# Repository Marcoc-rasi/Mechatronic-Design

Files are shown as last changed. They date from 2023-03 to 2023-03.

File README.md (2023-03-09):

# Mechatronic-Design
I worked together with a team of engineers on a robot that picks up tennis balls,the robot was made to function autonomously through the following systems
1- the power was supplied by a battery
2- the advance of the robot was carried out with direct current motors connected to a gear system to increase its torque, the speed and direction of rotation were controlled with an H bridge
3.- The blades work with a direct current motor, the rotation of the blades is activated through an infrared sensor, which detects when a ball enters the ramp and makes it rotate. This same sensor also helps us to stop the ramp in the starting position to insert a new ball.
4.- the robot has ultrasonic sensors which are used to detect obstacles and avoid them
5.- The color sensor located in the lower part of the car is used to determine the area of operation of the robot, we take samples of the colors of the interior of the tennis court, the lines of the court and the exterior of the court.
6.- to locate the balls and go to them, the robot uses an automatic vision system, which divides the view of the camera (cell phone) into two planes, if it finds a circular shape of the color of the tennis ball, in In one of these two planes, left or right, the robot will turn until it leaves the ball in the center of the division, in this way it always goes to a ball centering the entrance of the blades.

Two microcontrollers were used mainly due to two reasons, the first is regarding the ultrasonic sensors, since we had more than one, and these need a certain time to measure the distance, which left all the other processes pending. the vision and the ultrasonic sensors, these two were controlled by the esp32, and the vision was executed in OpenCV on the cell phone, sending a signal via bluetooth to the esp32 which communicated with Arduino through serial communication to generate the rotation of the robot

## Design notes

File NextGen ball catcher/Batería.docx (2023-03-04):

Batería:

Opciones:

- Power Bank
- Arreglo de Baterías 18650

Power Bank

Características:

5V

Capacidad: ~

Arreglo de Baterías 3S:

Voltaje: 3.7*3=11.1V

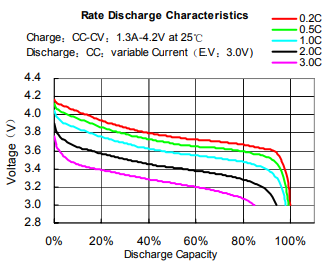
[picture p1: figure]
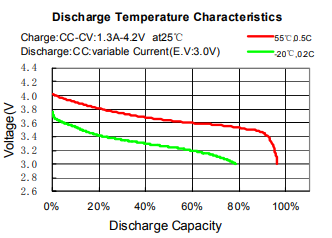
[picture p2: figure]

Estimaciones de porcentaje de carga de batería 18650

% de carga | Voltaje [V]
0 | 3 a 3.35
25 | 3.36 a 3.39
50 | 3.4 a 3.56
75 | 3.57 a 3.69
100 | >3.7

Estimaciones de porcentaje de carga para configuración 3S

% de carga | Voltaje [V]
0 | 9 a 10.05
25 | 10.06 a 10.17
50 | 10.18 a 10.68
100 | > 11.1

Nivel de carga de la batería950

Opciones:

- Módulo de nivel de carga de batería
- Medidor de voltaje / mostrar en GUI
- Arreglo de LEDs y Diodos Zener

Módulo de nivel de carga de batería | Medidor de voltaje | Arreglo de LEDs y Diodos Zener
- Para Baterías de Litio - Sólo requiere instalación - Costo estimado:$64 | - Para cualquier tipo de batería - Requiere instrumentación e implementación - Costo estimado: | - Para cualquier tipo de batería - Requiere cálculos - Costo estimado $25

Módulo de nivel de carga de batería

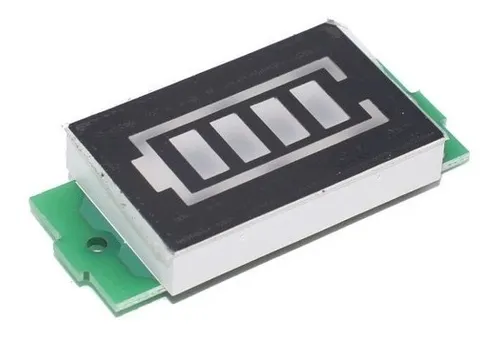
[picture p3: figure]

Medidor de voltaje

Arreglo de LEDs y Diodos Zener

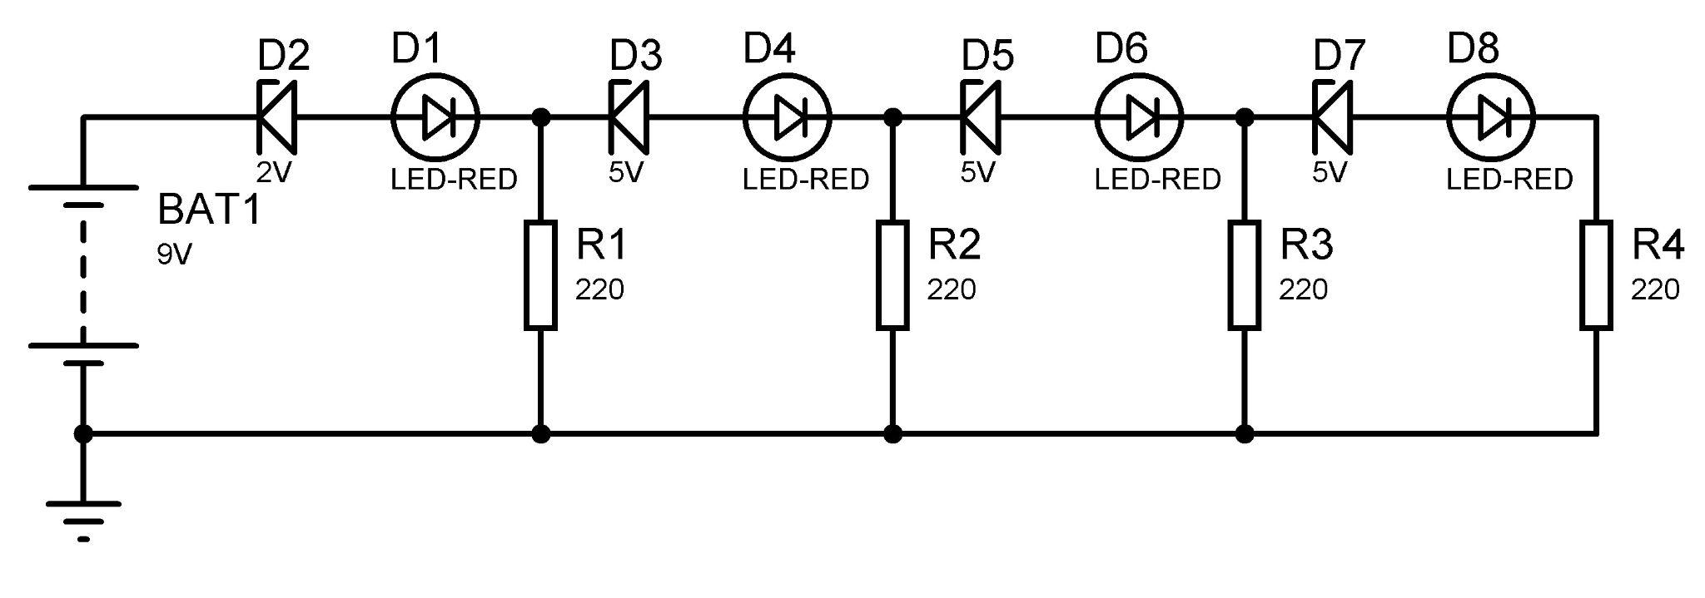
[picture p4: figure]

Microsoft Word - 18650H-2600mAh.doc (ineltro.ch) (https://www.ineltro.ch/media/downloads/SAAItem/45/45958/36e3e7f3-2049-4adb-a2a7-79c654d92915.pdf)

Indicador Led Carga De Bateria Litio Configurable Hasta 8s | MercadoLibre (https://articulo.mercadolibre.com.mx/MLM-754046522-indicador-led-carga-de-bateria-litio-configurable-hasta-8s-_JM)

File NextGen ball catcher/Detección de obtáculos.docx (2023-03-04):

Detección de obstáculos

Alternativas

- Módulo infrarrojo
- Circuito infrarrojo
- Láser

Módulo infrarrojo | Circuito infrarrojo | Módulo Láser
- Implementación sencilla - Distancia variable - Costo: $67 | - Requiere armado del circuito - Costo: $10 | - Implementación sencilla - Costo: 25

Módulo infrarrojo:

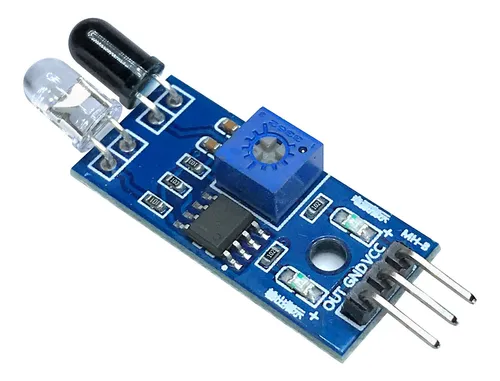
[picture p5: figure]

Módulo De Sensor Ir Infrarrojo Detector Obstaculos Arduino | MercadoLibre (https://articulo.mercadolibre.com.mx/MLM-826296559-modulo-de-sensor-ir-infrarrojo-detector-obstaculos-arduino-_JM)

Circuito Infrarrojo

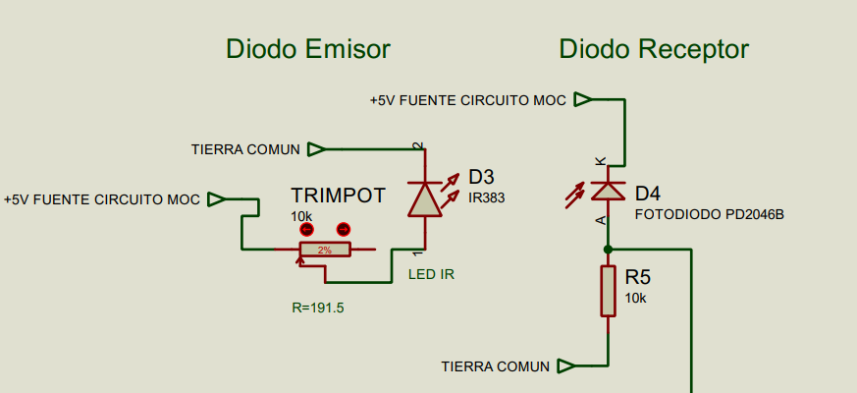
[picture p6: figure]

Láser

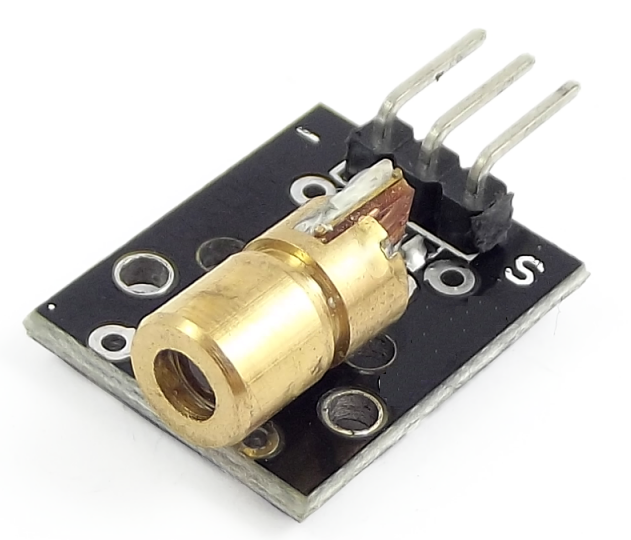
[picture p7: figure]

Módulo Sensor Laser KY-008 | SANDOROBOTICS (https://sandorobotics.com/producto/hr0021/)

Se seleccionó la opción del circuito de sensores infrarrojos, por el costo y la sencillez de armado y diseño, este circuito se pondrá a prueba para calibrar su funcionamiento

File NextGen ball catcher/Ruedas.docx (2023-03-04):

Descripción de la cancha

El área de trabajo del robot es una mitad de la cancha de tenis la cual cuenta con una superficie despejada, lisa y limpia, que no presenta irregularidades de ningún tipo debido a la seguridad de los deportistas. En la siguiente figura se muestra un ejemplo de cancha de tenis.

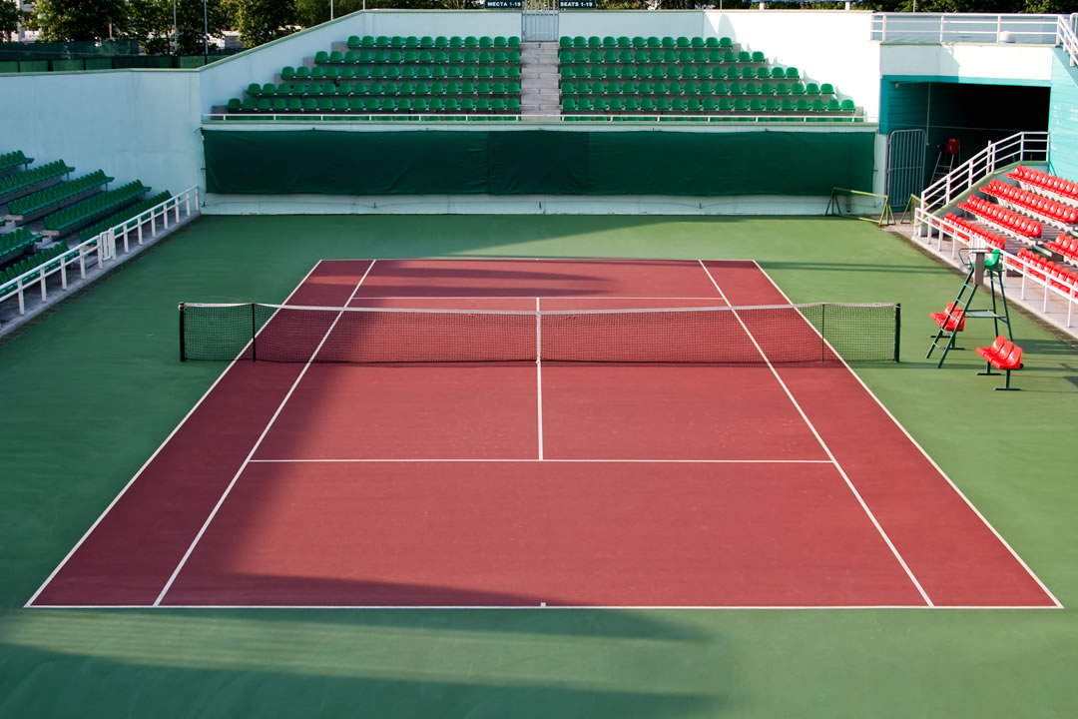
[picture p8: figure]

Comparativa de los diferentes tipos de ruedas

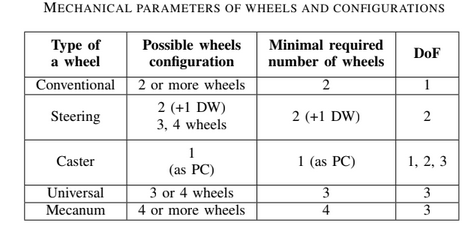
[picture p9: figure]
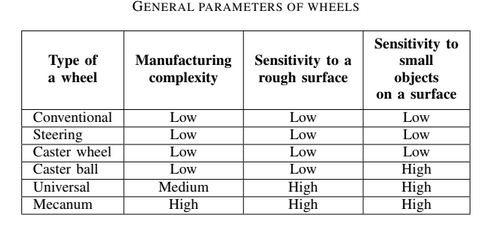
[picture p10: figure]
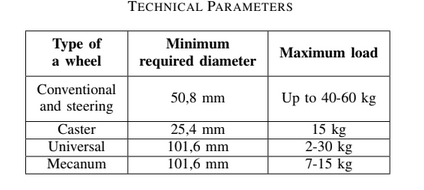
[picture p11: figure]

Selección de ruedas

Con ayuda de la comparativa se pudo observar que las ruedas que mejor se adaptan al prototipo de robot recoge pelotas de tenis son las convencionales, omnidireccionales y locas, debido a la que soportan mayor carga, su manufactura no es compleja por lo que los costos a comparación de las mecanum bajan significativamente, también soportan superficies más ásperas, como las canchas de tenis y son más resistentes que unas mecanum. Sin embargo, es necesario ver cuál es la combinación que soluciona mejor y con un menor costo la necesidad del robot.

Ruedas en el mercado

Convencionales

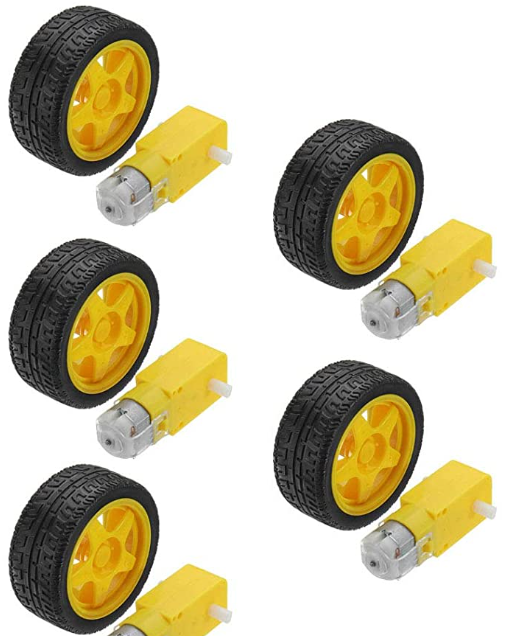
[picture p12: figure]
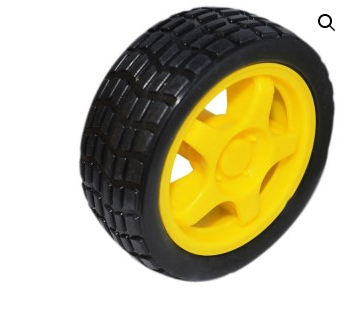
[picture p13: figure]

DollaTek 5 ruedas de plástico robot de coche inteligente con motor | Par de Llantas para Motorreductor de Plástico 65x26mm
Materiales: plástico + metal + goma. Relación de transmisión de reducción: 1:48 Voltaje de funcionamiento: 3-6 V. Par de torsión: 5.5kg/cm(6v) Tamaño: 70 x 27 x 23 mm (motor) Diámetro: 65 mm (rueda). Ancho: 27 mm (rueda) | Estas llantas o ruedas se usan comúnmente con los motorreductores de plástico, cuentan con unas dimensiones de de 65mm de diámetro exterior por 26mm de ancho. Son una opción perfecta para sustituir sus llantas gastadas así como para usarlas en motores de doble eje.
amazo-DollaTek (https://www.amazon.com.mx/DollaTek-pl%C3%A1stico-inteligente-engranaje-Arduino/dp/B081JM5WN8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) | Sandorobotics (https://sandorobotics.com/producto/hr0241/)

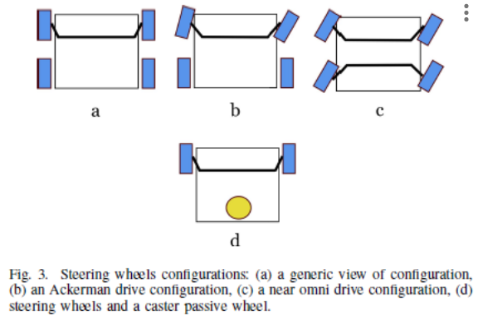
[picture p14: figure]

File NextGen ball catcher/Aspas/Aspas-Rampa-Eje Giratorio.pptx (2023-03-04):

## Aspas

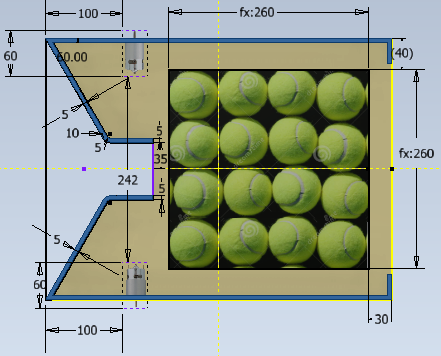
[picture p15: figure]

Independientemente del material las dimensiones serían:
Ancho: 3 mm
Largo: 100 mm
Alto: 80 mm
Eje Diametro 3 mm

Cambiar el diseño de la cabina donde entrarán las pelotas

## Material y Dimensión - Aspas y Eje

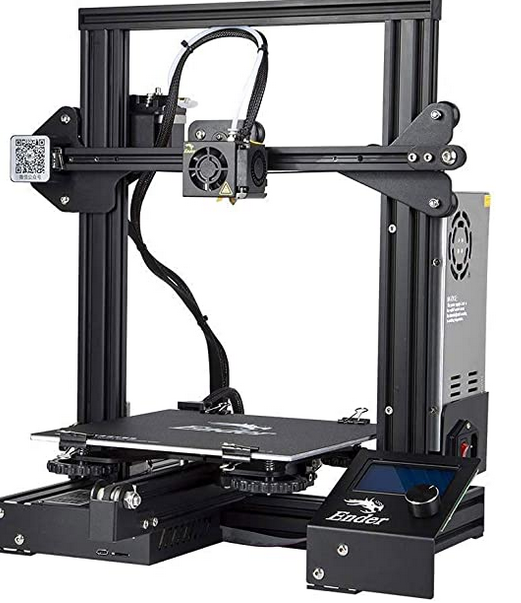
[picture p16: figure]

Impresión 3D: Ender 3

Detalles: Filamento Ácido poliláctico
- Precio - 430 $
- Dimensiones 1.75 mm diametro

- Diseños más complejos y elaborados
- Podemos elegir el grosor que más nos convenga.
- Da un aspecto profesional

- Más caro que las demás propuestas
- No muchos poseen una impresora 3D

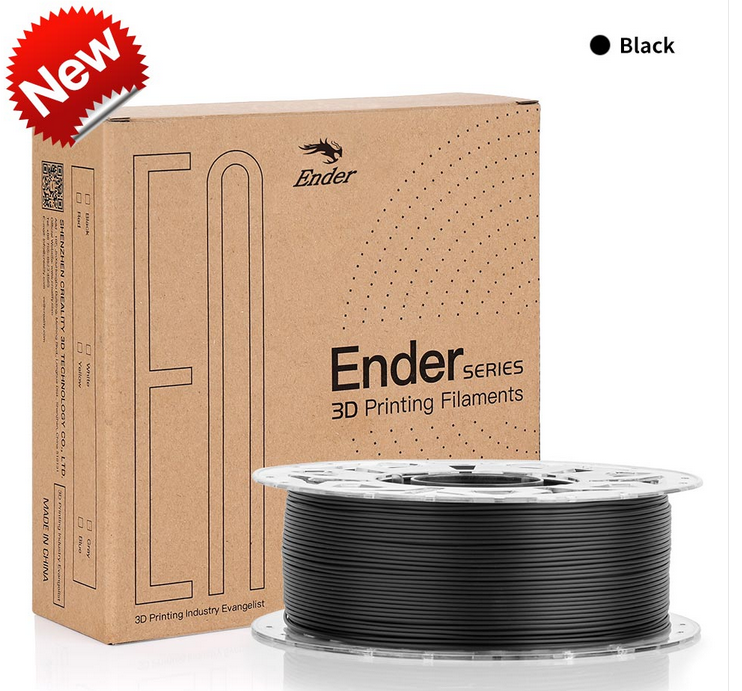
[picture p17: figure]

## Material y Dimensión - Aspas y Eje

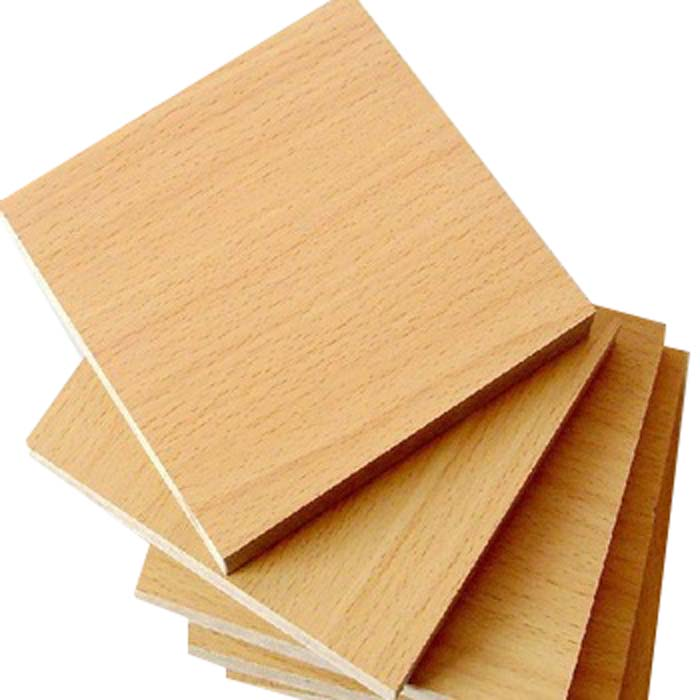
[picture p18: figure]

MDF

Detalles:
- Precio: 20 a 40 $ (depende del grosor)
- Dimensiones: 40 X 30 [cm]

- Económico
- Manejo fácil
- Podemos usar barnices o pinturas para una mejor presentación

- Baja resistencia al agua
- El uso de tornillos puede romper o dañar la pieza
- Es pesado

## Material y Dimensión - Aspas y Eje

Cristal Acrílico

Detalles:
- Precio: 95 a 110 $ (depende del grosor)
- Dimensiones: 40 X 30 [cm]

- De alta dureza
- Resistente al agua
- Su densidad volumétrica es de 1.1, su densidad equivale a un 43% la densidad del aluminio (https://www.ecured.cu/Aluminio).

- Los cambios de temperatura afectan las dimensiones del material.
- Impacto constante podría deformar la pieza.

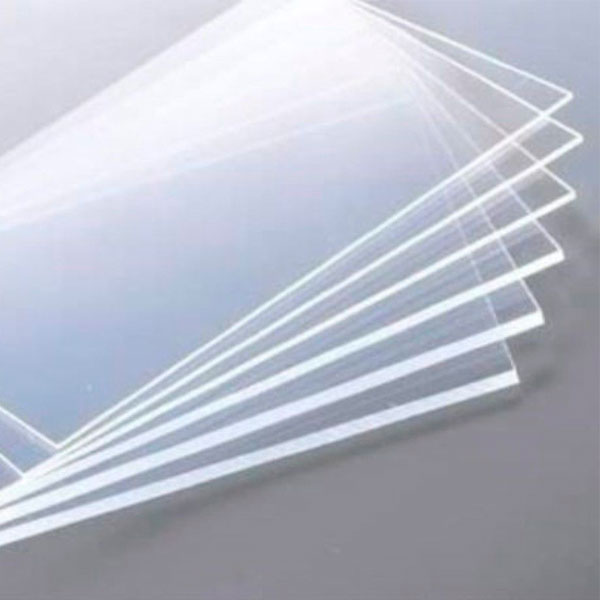
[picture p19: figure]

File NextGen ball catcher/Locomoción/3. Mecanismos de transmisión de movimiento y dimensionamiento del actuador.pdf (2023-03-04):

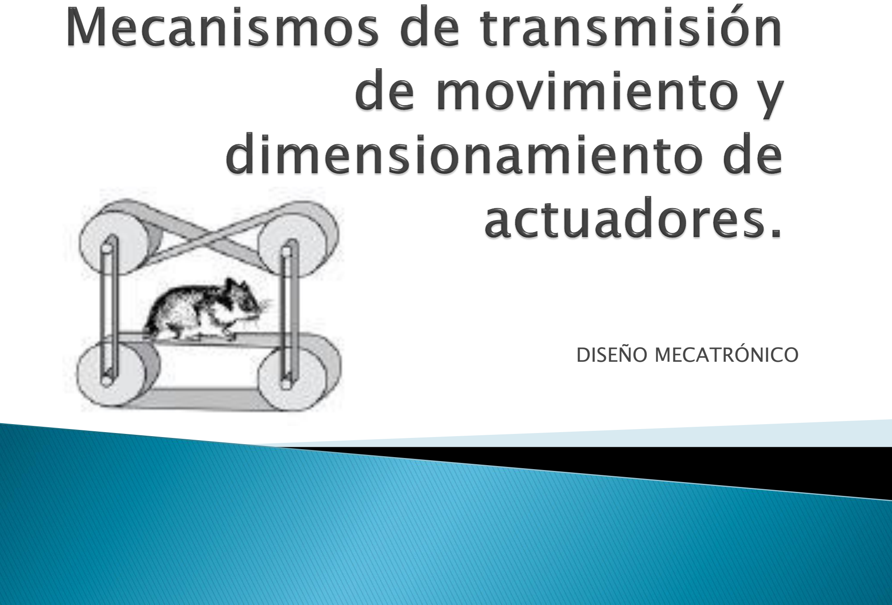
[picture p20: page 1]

DISEÑO MECATRÓNICO

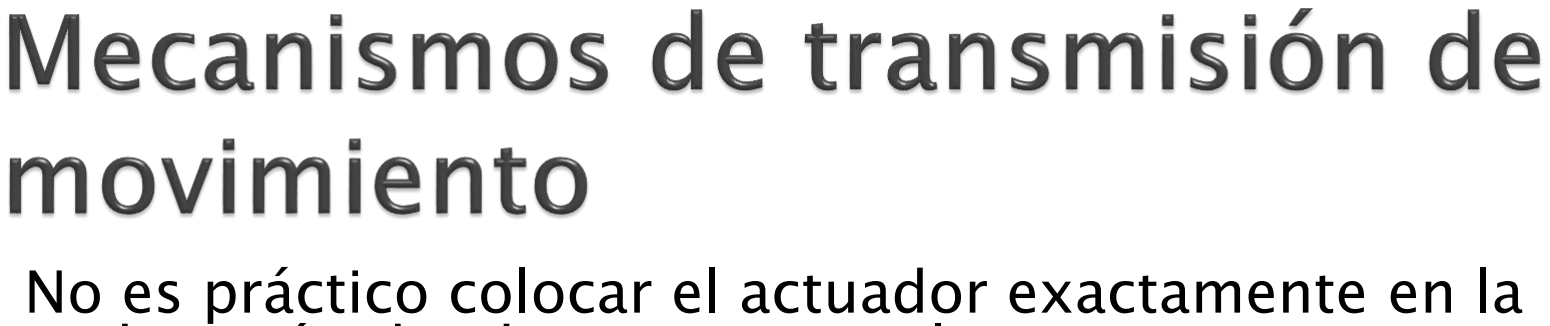
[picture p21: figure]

No es práctico colocar el actuador exactamente en la ubicación donde se necesita el movimiento.

- Los mecanismos de transmisión de movimiento realizan dos funciones distintas:
1. Transmiten movimiento del actuador a la herramienta cuando el actuador no se puede diseñar en la misma ubicación que la herramienta con el tipo de movimiento deseado.
2. Aumentan o reducen el par de torsión y la velocidad entre los ejes de entrada y salida, al tiempo que mantienen la conservación de potencia entre la entrada y la salida (menos las perdidas)

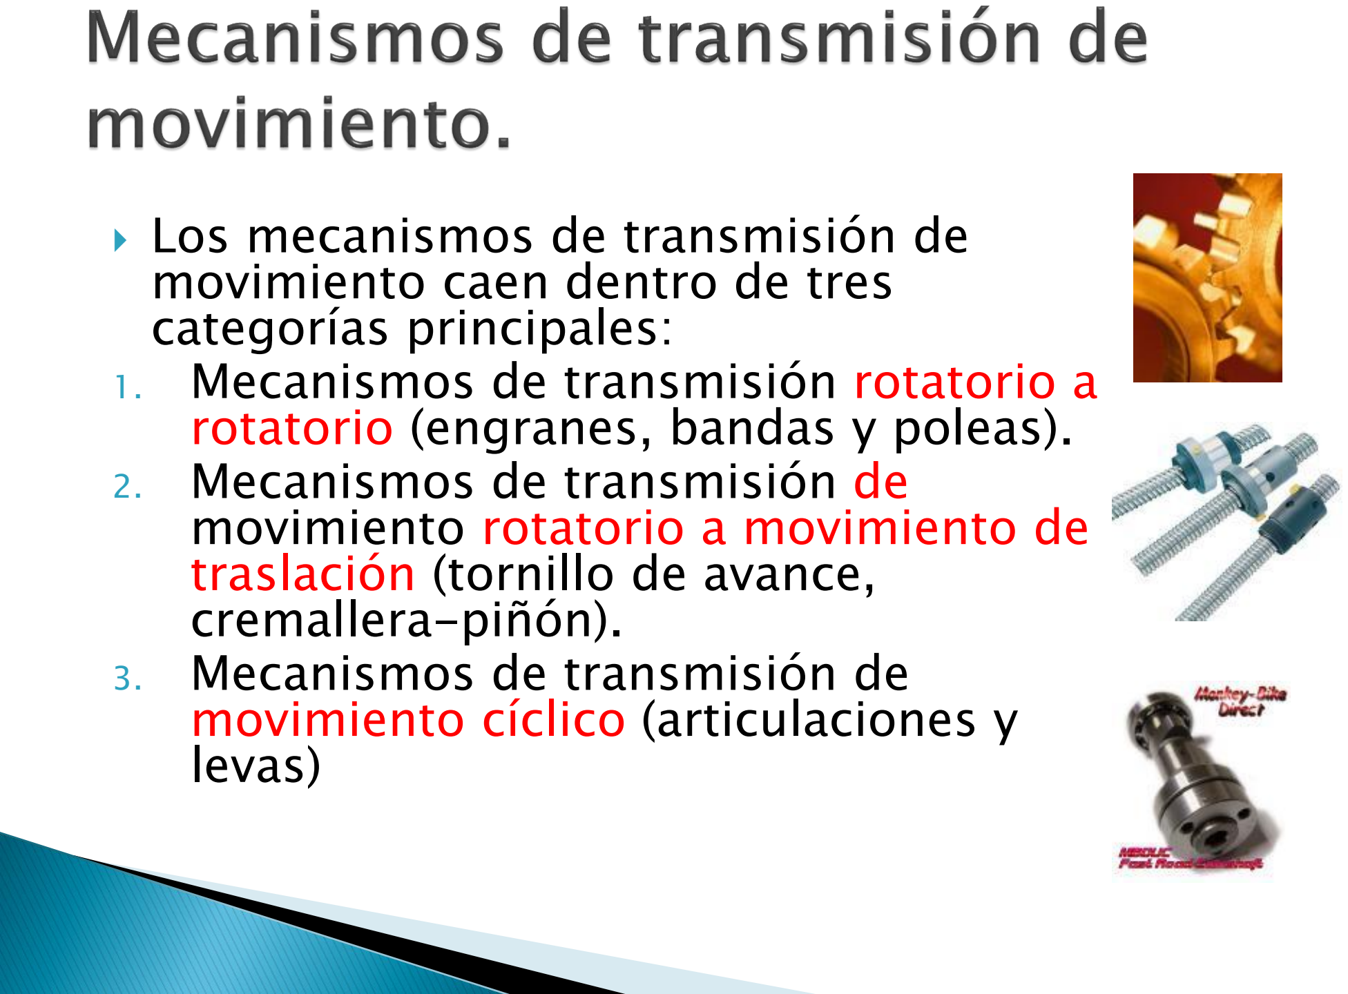
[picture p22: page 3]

- Los mecanismos de transmisión de movimiento caen dentro de tres categorías principales:
1. Mecanismos de transmisión rotatorio a rotatorio (engranes, bandas y poleas).
2. Mecanismos de transmisión de movimiento rotatorio a movimiento de traslación (tornillo de avance, cremallera-piñón).
3. Mecanismos de transmisión de movimiento cíclico (articulaciones y levas)

- Si el mecanismo fuera perfecto:
Pent=Psal
- Pero la eficiencia ŋ puede variar de 75 a 95% dependiendo del mecanismo de transmisión, entonces:
ŋ=(Psalida/Pent)

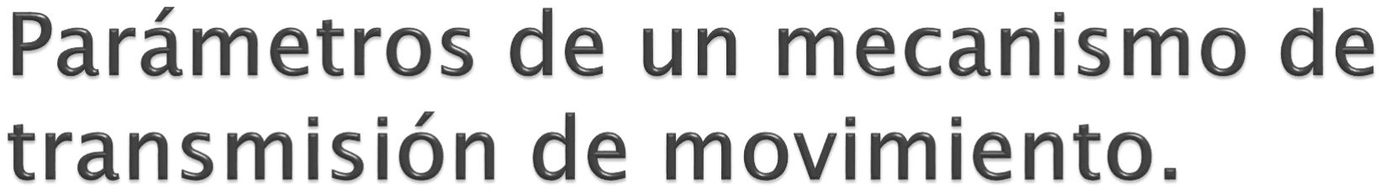
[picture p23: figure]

- Razón efectiva de engranes. También se le llama así cuando la conversión de movimiento no se realiza por engranes.
- Eficiencia. Para tornillo de bolas rotatorio a lineal: 0.9 y lineal a rotatorio de 0.8. Para tornillos de avance varía en función del ángulo.
- Juego. El juego está dado en unidades de minutos de arco, arcmin=1/60 grados en mecanismos rotatorios y en distancia lineal en mecanismos de traslación.
- Fricción de arranque. Fuerza de fricción entre los componentes móviles, es el par de torsión o fuerza mínima necesaria en el eje de entrada para mover el mecanismo.
- Manejabilidad en reversa.

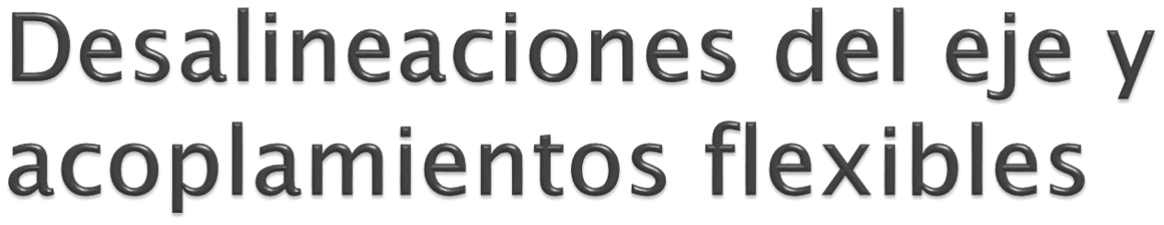
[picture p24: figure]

- Cualquier desalineación entre el actuador y mecanismo de transmisión resulta en cargas en los cojinetes, causaran vibraciones y mayor consumo de potencia del actuador.

Para reducir la desalineación se utilizan acoplamientos flexibles entre los ejes.

- Acoplamientos para transferencia grande de potencia entre ejes y motores.
- Acoplamiento para transferencia de precisión de movimiento a potencias bajas entre ejes y motores.

- Capacidad máxima y nominal del par de torsión.
- Rigidez torsional
- Desalineación axial máxima permitida
- Inercia y masa rotatoria del acoplamiento
- Diámetros de entrada y salida del eje
- Método de conexión de entrada y salida del eje (tornillo de fijación, amordazado con cuña)

- El actuador se puede basar en potencia eléctrica, hidráulica ó neumática. El tamaño del actuador se relaciona con su capacidad de potencia y debe ser lo bastante grande para mover el eje bajo condiciones de carga.
- La cuestión de dimensionamiento del actuador es la cuestión de determinar los requisitos para un eje bajo las peores condiciones de operación.

- Par de torsión máximo
- Velocidad máxima
- Precisión del posicionamiento requerida
- Parámetros del mecanismo de engranes: características de la razón de engranes, de su carga inercial y resistiva.
- Una vez que se determinan los requisitos de par y torsión, los requisitos de corriente y voltaje del sistema electrónico de potencia se determinan de manera directa.

- Hay tres puntos para determinar el dimensionamiento del actuador:
1. Determinar la inercia neta (puede ser en función de la posición del mecanismo de conversión de movimiento)
2. Determinar los pares de torsión de carga netos (puede ser una función de la posición del mecanismo de conversión de movimiento y de la velocidad)
3. Especificar el perfil del movimiento deseado.


Uno de los
mejores

Pros | Contras | Aplicaciones
Motores
de Pasos
Económico, puede ejecutar en lazo abierto, buen torque, limpio | Ruidoso y resonante, torque de alta velocidad mediocre, no apto para ambientes calientes, no apto para cargas variables

Posicionamiento,
micro movimientos

Servomoto
res de
Escobillas
DC

Económico,
velocidad
moderada, buen
torque de eje
inferior, drives
simples

Requiere
mantenimiento, no
es limpio, las
chispas de las
escobillas causan
EMI y peligro en
ambientes
explosivos

Control de
velocidad, control
de posición a alta
velocidad

Servomoto
res sin
Escobillas

No requiere
mantenimiento,
larga vida, sin
chispas, altas
velocidades, limpio,
callado, ejecuta sin
calentarse

Drives caros y
complicados

Robótica, tomar y
colocar,
aplicaciones de alto
torque

La selección de motor y diseño mecánico es una parte crítica en el diseño de su sistema de control de movimiento. Muchas compañías de motores ofrecen asistencia para elegir el motor correcto, pero es útil saber información básica sobre motores antes de empezar a buscar. La siguiente tabla describe diferentes tecnologías de motores.

- Investigar que es un motor de DC Brushless de 3 fases, como se realiza la secuencia de movimiento y realizar una simulación del movimiento del motor.


El estado inicial y final son de reposo.

Los movimientos se deben realizar en el menor tiempo posible.

Salvaguardar la integridad del objeto manipulado.

Evitar generar fuerzas de impacto durante la ejecución de los movimientos.

Evitar fuerzas que propicien un movimiento relativo entre el objeto y el mecanismo de sujeción.

dos; aspectos; principales:; las; particularidades; cinemáticas; del; 3. Perfil de trayectoria quintico.

La generación de trayectorias involucra
movimiento y la posición en el espacio
del objeto manipulado
1. Perfil de
trayectoria
trapezoidal.

2. Perfil de tercer
orden.


Primer
período
transitorio





Subsistema de
Desplazamiento

4,650 Kg.

Subsistema de
Salida Frontal

3,450 Kg.

Subsistema de
Gatos

3,000 Kg.

Subsistema de Giro

25,885 Kg.


- La elección mas sencilla es utilizar un polinomio en t:
- Uno de grado cero es una cte. -> no se movería
- Uno de grado uno es lineal, con lo cual su derivada no podría ser nula en algún punto.
- Uno de grado dos solo tiene un máximo y un mínimo con lo cual su derivada no podría anularse en dos puntos como se pide.

Posición

Tiempo

Velocidad

Tiempo

Aceleración


Tiempo

0

t
t t

0

t
t

t


θ t = a0 + a1t + a2t

2 + a3t

3

Cuanto valen los
coeficientes?

- Obtener los coeficientes de un perfil de quinto orden:

Un polinomio de quinto orden genera un perfil de jerk cuadrático, al contrario de un polinomio cúbico, que proporciona un perfil de jerk constante.


- Programar un perfil de velocidad de tercer orden o quinto orden para el movimiento de un motor de corriente directa, el cual debe llegar a la velocidad máxima en 1,2,3,4 y5 segundos.
- Se debe de observar en el osciloscopio el perfil de velocidad programado.
- La velocidad se puede medir con un motor conectado como generador o con otra salida PWM y un filtro RC


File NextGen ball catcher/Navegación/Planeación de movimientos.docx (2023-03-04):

Entrada: obstáculos | Cuantizado
Sin obstáculos | 0
Derecho | 1
Izquierdo | 2
Enfrente | 3
Atrás | 4

Entradas: Objetivo pelota | Cuantizado
Centrado | 0
Derecha | 1
Izquierda | 2
Sin objetivo | 3

Entradas: Detección de límite de cancha | Cuantizado
Sin lectura | 0
Ambos sensores | 1

Estado | Entradas | | | Estado Siguiente
| Obs | Obj P | Lim C
Inicio | 0 | 0 | 0 | Adelante
Inicio | 0 | 0 | 1 | Atrás
inicio | 0 | 1 | 0 | Derecha
inicio | 0 | 1 | 1 | Atrás
inicio | 0 | 2 | 0 | Izquierda
Inicio | 0 | 2 | 1 | Atrás
Inicio | 0 | 3 | 0 | Detener
Inicio | 0 | 3 | 1 | Detener
Inicio | 1 | 0 | 0 | Izquierda
Inicio | 1 | 0 | 1 | Atrás
Inicio | 1 | 1 | 0 | Izquierda
Inicio | 1 | 1 | 1 | Atrás
Inicio | 1 | 2 | 0 | Izquierda
Inicio | 1 | 2 | 1 | Atrás
Inicio | 1 | 3 | 0 | Detener
Inicio | 1 | 3 | 1 | Detener
Inicio | 2 | 0 | 0 | Derecha
Inicio | 2 | 0 | 1 | Atrás
Inicio | 2 | 1 | 0 | Derecha
Inicio | 2 | 1 | 1 | Atrás
Inicio | 2 | 2 | 0 | Derecha
Inicio | 2 | 2 | 1 | Atrás
Inicio | 2 | 3 | 0 | Detener
Inicio | 2 | 3 | 1 | Detener
Inicio | 3 | 0 | 0 | Atrás
Inicio | 3 | 0 | 1 | Atrás
Inicio | 3 | 1 | 0 | Atrás
Inicio | 3 | 1 | 1 | Atrás
Inicio | 3 | 2 | 0 | Atrás
Inicio | 3 | 2 | 1 | Atrás
Inicio | 3 | 3 | 0 | Detener
Inicio | 3 | 3 | 1 | Detener
Inicio | 4 | 0 | 0 | Adelante
Inicio | 4 | 0 | 1 | Izquierda
Inicio | 4 | 1 | 0 | Derecha
Inicio | 4 | 1 | 1 | Derecha
Inicio | 4 | 2 | 0 | Izquierda
Inicio | 4 | 2 | 1 | Izquierda
Inicio | 4 | 3 | 0 | Detener
Inicio | 4 | 3 | 1 | Izquierda

Como ya vimos que de esta manera se emplean muchos estados, lo decidimos simplificar a 3 estados generales, con lógica de orden 0.


En este caso, el comportamiento de mayor prioridad será el de la detección del área de trabajo, que delimitará al de la detección de obstáculos, precedido de la detección de pelotas.

Modo búsqueda:

Centrar el objetivo dependiendo de dónde se localiza la pelota.

Modo Navegación;

Navegar hacia el frente.

Modo obstáculo.

Si el obstáculo representa el área de trabajo, realizar un retroceso, y giro a la derecha.

Si el obstáculo se detecta a los lados del robot, realizar un movimiento contrario al obstáculo, (ej, obs derecha, giro izquierda). En caso se encuentre enfrente el obstáculo, retroceder y luego hacer un giro derecho.

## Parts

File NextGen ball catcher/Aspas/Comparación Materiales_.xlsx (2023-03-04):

Características | MDF a 3 mm espesor | Ácido Poliláctico (PLA) | Resina estándar fotopolímero ELEGOO | Filamento ABS (dura)
Definición | Es un aglomerado elaborado con fibras de madera aglutinadas con resinas sintéticas mediante fuerte presión y calor, en seco, hasta alcanzar una densidad media. | El ácido poliláctico (PLA), es un biopolímero termoplástico cuya molécula precursora es el ácido láctico. Debido a su biodegradabilidad, propiedades de barrera y biocompatibilidad, éste biopolímero ha encontrado numerosas aplicaciones ya que presenta un amplio rango de propiedades, desde el estado amorfo hasta el estado cristalino. | La resina de fotopolímero ELEGOO es un tipo de polímero que cambia sus propiedades físicas cuando se introduce en la luz. En el caso de la impresión 3D, estas son resinas de plástico líquido que se endurecen cuando se expone a una fuente de luz, como un láser, una lámpara, un proyector o diodos emisores de luz (LED) y la mayoría de estas fuentes de luz irradian luz ultravioleta (UV). | El filamento de ABS tiene propiedades significativas que lo convierten en una gran opción, como su resistencia y el hecho de que es ligero, mientras que también puede manejar muchos productos químicos diferentes. El material ABS también es reciclable, lo que significa que es mejor para el medio ambiente que algunos otros plásticos al causar menos residuos.
Densidad | > 0.0008 g/mm3 | 0.0012 g/mm3 | 0.001119 g/mm3 | 0.001 g/mm3
Resistencia a la Tracción | 17.64 MPa | 57.8 MPa |  | 41 - 45 MPa
Resistencia a la Flexión | > 23 MPa | 55.3 - 103 MPa | 59 - 70 MPa | 49 MPa
Módulo de Elasticidad | >2700 MPa | 3300 MPa |  | 1700 MPa
Precios (pesos) | 20 $ - 40 X 30 [cm] https://pumanet.com.mx/ | 430$ - 1Kg https://www.creality3dofficial.com/products/1kg-ender-pla-filament | 863$ - 500 g https://www.amazon.com.mx/ELEGOO (https://www.amazon.com.mx/ELEGOO%C2%AE-Resina-est%C3%A1ndar-fotopol%C3%ADmero-impresi%C3%B3n/dp/B07FCLLNFY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) | 293.84$ - 1kg https://www.amazon.com.mx/Filamento-impresora
Cualidades | Se caracterizan por su uniformidad y homogeneidad en todo su espesor, sus caras son lisas y suaves, no presentan problemas para su corte y se mecanizan y molduran con mucha facilidad. | El PLA ofrece una buena resistencia a la tracción y calidad superficial, facilita el trabajo a altas velocidades de impresión, crea piezas de alta resolución. | Una resina versátil para cualquier tipo de uso desde estético como para crear prototipos funcionales de dureza baja, por eso es muy fácil de encontrar en el mercado y su precio es accesible | Las propiedades físicas del filamento de ABS son muy buenas, como un alto nivel de resistencia a la tensión y rigidez. Se utiliza para fines mecánicos y debido a sus propiedades eléctricas.
Otros : | Excelente pintabilidad y moldurabilidad, que permite excelentes terminaciones, con un importante ahorro de pintura y un menor desgaste de herramientas. | Es biodegradable | Funciona con múltiples impresoras 3D LCD/DLP | El ABS está más indicado cuando se busca la fuerza en el resultado o cuando lo que se va a imprimir va a quedar expuesto a temperaturas extremas.
 | Densidad y comportamiento uniforme del tablero, ideal para moldurar, curvar, fijar, fresar etc. | Se usa para herramientas domésticas, juguetes, proyectos educativos, objetos de exposición, prototipado, modelos arquitectónicos y también métodos de fundición a la cera perdida para crear piezas de metal |  | Por lo tanto, cuando se trata de imprimir y usar una impresora 3D FFF, el material ABS es una elección popular. Esto se debe a la forma en que el material ABS puede ser utilizado para crear rápidamente prototipos a un bajo costo y una mayor eficiencia.
Contras | Baja resistencia al agua | Su uso no es propiamente para ingenieria mecánica, más para envases y embotellados plásticos | Tiene un acabado suave y con baja resistencia mecánica. | Cuando se imprime con material ABS y no se utiliza una cámara cerrada puede causar problemas de deformación. Una cámara mantiene las fluctuaciones de la temperatura ambiente al mínimo
 | El uso de tornillos con mucha presión puede dañar la pieza
LINKS: | https://www.scielo.cl/scielo.php?script=sci_arttext&pid=S0718-221X2002000200008
 | https://www.mexpolimeros.com/pla.html
 | https://3dlaboratorio.es/plastic-pla.htm
 | https://www.ensingerplastics.com/es-br/semielaborados/plastico/tecaran-abs-grey
 | https://tractus3d.com/es/materials/abs/
 | https://www.impresoras3d.com/el-material-de-impresion-abs-y-sus-caracteristicas/

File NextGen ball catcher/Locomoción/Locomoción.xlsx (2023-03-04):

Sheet: Ruedas
Criterios de desición
 | Comparativa de las diferentes configuraciones |  |  | Parámetros generales |  |  | Parámetros técnicos
Tipo de llanta | Posible configuración de ruedas | Número mínimo de ruedas | DoF | Complejidad de armado | Sensibilidad a la superficie | Sensibilidad a objetos en la superficie | Mínimo diámetro requerido | Carga Máxima
Convencional | 2 o más ruedas | 2 | 1 | Baja | Baja | Baja | 50,8 [mm] | Up to 40-60 [kg]
Rueda Giratoria | 2 (+1 DW). 3, 4 ruedas | 2 (+1 DW) | 2 | Baja | Baja | Baja | 50,8 [mm] | Up to 40-60 [kg]
Rueda Giratoria 2 | 1 (es PC) | 1 (es PC) | 1,2,3 | Baja | Baja | Alta | 25,4 [mm] | 15 [kg]
Rueda omnidireccional | 3 o 4 ruedas | 3 | 3 | Media | Alta | Alta | 101,6 [mm] | 2-30 [kg]
Rueda Mecanum | 4 o más ruedas | 4 | 3 | Alta | Alta | Alta | 101,6 [mm] | 7-15 kg
Cotizaciones
 | Cotización 1 |  |  | Cotización 2 |  |  | Cotización 3
Tipo | Link | Descripción | Precio | Link | Descripción | Precio | Link | Descripción | Precio
Convencional | Sandorobotics (https://sandorobotics.com/producto/hs0376/) | Par de Llantas para Motorreductor de Plástico 65x26mm | $60 | Amazon-DollaTek (https://www.amazon.com.mx/DollaTek-pl%C3%A1stico-inteligente-engranaje-Arduino/dp/B081JM5WN8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) | 5 llantas con motorreductor incluido (Relación de transmisión de reducción: 1:48 Voltaje de funcionamiento: 3-6 V. ) | $336 | Kinetronica (http://kinetroni.com/index.php?product_id=116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) |  | $25
 | Sandorobotics (https://sandorobotics.com/producto/hs0376/) | Par de Llantas para Motorreductor de Plástico 65x18mm | $60
 | Kinetronica (http://kinetroni.com/index.php?product_id=757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) | Par de llantas hechas con plástico ABS y hule de alta tracción | $50
Giratoria | UNIT (https://uelectronics.com/producto/rueda-loca-nylon-con-25mm-para-carrito/) | Rueda Loca Nylon con 25mm Para Carrito | $28 | Mercado Libre (https://articulo.mercadolibre.com.mx/MLM-932841508-rueda-loca-nylon-con-25mm-para-carrito-_JM) |  | $55
 | Kinetronica (http://kinetroni.com/index.php?page=shop.product_details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) | Rueda giratoria de metal de 1 1/2 pulg | $60 | Kinetronica (http://kinetroni.com/components/com_virtuemart/shop_image/product/rueda_loca_de_pl_51dc6d24c51d4.jpg) | Rueda giratoria de plástico de 1 1/2 pulg Ligera y reduce mucho la fricción incluye accesorios Separadores de 1/16" y 1/8" fabricado con plástico ABS | $62
Omnidireccional | Mercado Libre (https://articulo.mercadolibre.com.mx/MLM-880229758-ruedas-omni-de-90-38-mm-rueda-omnidireccional-de-_JM) | Diámetro: 1.5 puadas (38 mm) Ancho: 23,4 Material del fuselaje: plástico Peso neto: 20 g Material del rodillo: plástico Número de rodillos: 8 Carga: 2 kg | $312 | Mercado Libre (https://articulo.mercadolibre.com.mx/MLM-1355472427-2x-58mm-dia-ruedas-omnidireccionales-para-robot-tank-_JM) | Diámetro: 58 mm Diámetro interior: 16 mm. material: caucho, plástico ABS Carga: 3 kg Diámetro del rodillo: 13 mm Peso: 60g | $660 | Sandorobotics (https://sandorobotics.com/producto/276-1902/) | Diámetro de 2.75″ 14 rodillos por rueda Compatible con todos los ejes cuadrados VEX de 0,125″ 2 piezas por paquete | $680
Mecanum | Mercado Libre (https://articulo.mercadolibre.com.mx/MLM-961127457-rc-ruedas-omnidireccionales-70mm-accesorio-para-mecanum-rc-_JM) | Material: Acrílico Tamaño (Diámetro x H): aprox. 70 x 30 mm /2.75x1.18 puadas | $349
Conclusión
Con ayuda de la comparativa se pudo observar que las ruedas que mejor se adaptan al prototipo de robot recoge pelotas de tenis son las convencionales, omnidireccionales y locas, debido a la que soportan mayor carga, su manufactura no es compleja por lo que los costos a comparación de las mecanum bajan significativamente, también soportan superficies más ásperas, como las canchas de tenis y son más resistentes que unas mecanum. Sin embargo, es necesario ver cuál es la combinación que soluciona mejor y con un menor costo la necesidad del robot.
Propuesta
Una configuración con dos llantas convencionales al frente y dos ruedas giratorias en la parte posterior

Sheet: Motor
 | Cotización 1 |  |  | Cotización 2 |  |  | Cotización 3
Motorreductor | Link | Descripción | Precio | Link | Descripción | Precio | Link | Descripción | Precio
 | Kinectronica (http://kinetroni.com/index.php?product_id=140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) | Compacto y económico reducción 180:1 80 rpm 2.1 kg-cm Salida a eje tipo D 80mA sin carga 800mA con carga Más información en: | $140
 | UNIT (https://uelectronics.com/producto/motorreductor-3v-6v-escuadra-l-con-eje-de-metal/) | Voltaje de operación: 6V corriente sin carga: ≤200mA velocidad sin carga: 200 ± 10% rpm Voltaje de operación: 3V corriente sin carga: ≤150 mA velocidad sin carga: 90 ± 10% rpm Tamaño: 65 x 23 x 18 mm Peso: 80 gramos Relación de transmisión: 1:120 Par Maximo: 800 gF x cm Forma de L o de angulo de recto (90°) | $41 | Kinetronica (http://kinetroni.com/index.php?product_id=1008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) |  | $65
 | Mercado Libre (https://articulo.mercadolibre.com.mx/MLM-609407563-motorreductor-de-doble-eje-recto-_JM) | Voltaje de alimentación mínimo: 3 V Voltaje de alimentación máximo: 6 V Corriente sin carga (3 V): 110 - 130mA Corriente sin carga (6 V): 130 - 150mA Velocidad sin carga (3 V): 125 RPM + / - 10 % Velocidad sin carga (6 V): 230 RPM + / - 10 % Relación de caja de cambios: 48: 1 Número de ejes: 2 Temperatura de operación mínima: -10 °C Temperatura de operación máxima: 65 °C Dimensiones: 42 mm X 22.7 mm X 47.8 mm Forma: Recto Material: Plástico Color: Amarillo | $49 | Mercado Libre (https://articulo.mercadolibre.com.mx/MLM-791853297-2-piezas-motorreductor-recto-481-motor-2-ejes-carro-arduino-_JM) | 2 piezas | $67 | Kinetronica (http://kinetroni.com/index.php?product_id=1007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) |  | $29
 | Kinetronica (http://kinetroni.com/components/com_virtuemart/shop_image/product/100_1_Metal_Gear_55a7df4f9646a.jpg) | Motor con reducción 100:1 37mm de diametro 57mm de largo. Torque 16 kg-cm corriente máxima 5A 500rpm @ 12V 100mA | $450
 | Kinetronica (http://kinetroni.com/index.php?product_id=141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) | 1000:1 @6V 14rpm 40mA sin carga. 5kg-cm 0.36A con carga 298:1 @6V 100rpm 120mA sin carga. 5kg-cm 1.6A con carga 298:1 @6V 45rpm 40mA sin carga. 2.9kg-cm 1.6A con carga 250:1 @6V 120rpm 120mA sin carga. 4.3kg-cm 1.6A con carga 210:1 @6V 140rpm 70mA sin carga. 3.6kg-cm 1.6A con carga 100:1 @6V 320rpm 120mA sin carga. 2.2kg-cm 1.6A con carga 75:1 @6V 400rpm 70mA sin carga. 1.6kg-cm 1.6A con carga 50:1 @6V 625rpm 120mA sin carga. 1.1kg-cm 1.6A con carga 30:1 @6V 1000rpm 120mA sin carga. 0.6kg-cm 1.6A con carga 10:1 @6V 3000rpm 120mA sin carga. 0.3kg-cm 1.6A con carga 10:1 @6V 1300rpm 40mA sin carga. 0.2kg-cm 0.36A con carga | $315 (varía según la reducción)

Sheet: Cálculos
 | Kinetronica (http://kinetroni.com/index.php?product_id=757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) | Par de llantas hechas con plástico ABS y hule de alta tracción. 60 [mm] diámetro | $50
Giratoria | UNIT (https://uelectronics.com/producto/rueda-loca-nylon-con-25mm-para-carrito/) | Rueda Loca Nylon con 25 [mm] Para Carrito | $28 | Mercado Libre (https://articulo.mercadolibre.com.mx/MLM-932841508-rueda-loca-nylon-con-25mm-para-carrito-_JM) |  | $55 | Yo tengo una
radio [m] | 0.03
W_robot [kg] | 3
W_pelota [kg] | 0.06 |  | T= | 0.06895449 | Nm
W_carga [kg] | 0.6 |  |  | 6.895449 | Ncm
Gravedad [m/s^2] | 9.81 |  |  | 0.7031401141 | kgcm
Coeficiente de fircción dinámico [1] | 0.1
# llantas con motor | 2
Densidad MDF (5.5 mm) | 830 | kg/m^3
Densidad MDF(3 mm) | 820 ± 50 | kg/m^3
Estimación del peso
Chasis | 2.336 | kg
Electrónica (incluída la batería) | 0.75
Pelotas | 0.6
Masa de respaldo | 1
Peso total | 4.686

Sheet: Propuestas
Locomoción
 | Diferencial | Sincronizado | Tipo carro | Dirección deslizante | Articulada | Pivote | Omnidireccional
Descripción | Consta de dos ruedas impulsoras con actuadores independientes. Usulamente están al frente del robot en cada lado. | Compuesto por tres a cuatro ruedas y dos motores uno para girar las ruedas y otro para rotar las ruedas y cambiar de dirección | Cuenta con un par de ruedas conductoras y otro (o una en el caso del triciclo) par de ruedas conducidas. Las ruedas frontales conducidas unen las dos funciones (dirección y empuje) además de proveer de un radio de giro menor. | Empleado en tanque y bulldozers. Ocupan llantas u oruga de que ambos lados impulsan al robot en diferentes sentidos, para así cambiarlo de dirección, haciendo que se delice. | Similar al tipo carro o con la singularidad de que la dirección se controla mediante la deformación del chasis. | Consta de dos partes 1) un chasis de 4 ruedas de un solo GDL (giro) y una plataforma giratoria que se alza o baja para llevar acabo el cambio de dirección girando la plataforma. | El tipo de ruedas da lugar a otro tipo de locomoción, que consta de 3 o 4 llantas, todas actuadas cuya disposicón puede ser como las mostradas en la figura.
Motores | 2 | 2 | 2 | 2 | 2 | 3 (para girar ruedas, rotar plataforma y subir y bajar) | 3 o 4 (depende de las llantas)
Tipo | No-holonómico | Holonímico | No-holonómico | Holonímico | No-holonómico | Holonómico | Holonómico
Ventajas | Simplicidad | Control | Simplicidad pero con gran control sobre el mecanismo de vuelta. | Sistema de dirección implícito / Mejor tracción | Simplicidad pero con gran control sobre el mecanismo de vuelta. | Control | Sistema de dirección implícito / Mejor tracción
Desventajas | Control (complicado ir en línea recta) | Complejidad (mecanismo) | Planeación de movimientos | Control (línea recta) / Odometría | Planeación de movimientos | Versatilidad / Complejidad | Control / Odometría
Tipos de ruedas
Impulsora | Convencional |  | Convencional
Libre | De bola (mejor) / Loca |  | De bola (mejor) / Loca
Fuentes: | Lab-Rats Course MIT (https://groups.csail.mit.edu/drl/courses/cs54-2001s/roborats.html)
Motores | Tipo | RPM | Reducción | Torque [Kg cm] | Voltaje [V] | Corriente [mA] |  | Potencia [W] | Peso [Kg] | Precio | Proveedor | Referencias
Motorreductor |  |  |  |  |  | Sin carga | Máxima
 |  | 85 | 380:1 | 5 | 6 | 100 | 1500 | 1.1 | 0.01 | 500 | Sandorobotics (https://sandorobotics.com/producto/3069/) | Pololu (https://www.pololu.com/product/4824)
 |  | 100 | 298:1 | 3.4 | 6 | 100 | 1500 | 1 | 0.01 | 500
 |  | 150 | 210:1 | 3 | 6 | 70 | 1600 | 1.1 | 0.01 | 500
 |  |  |  |  |  |  |  |  |  | 122 | Ag Electrónica (https://www.agelectronica.com/detalle.php?p=OKY5022-5)
 |  |  |  |  |  |  |  |  |  | 315 | Kinetronica (http://kinetroni.com/index.php?page=shop.product_details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)
Con Encoder |  | 500 | 20.4:1 | 6 | 12 | 300 | 5600 | - | 0.098 | 1250
 |  | 99 | 99:1 | 15 | 6 | 420 | - | 3.9 | - | 400 | Kinetrónica (http://kinetroni.com/index.php?page=shop.product_details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)
 |  | 110 | 34:1 | 5.2 | 6 | 600 | 1100 | 3.1 | - | 550 | Mercado Libre (https://articulo.mercadolibre.com.mx/MLM-601188201-motor-cd-motorreductor-134-encoder-52-kgcm-110-rpm-6v-12v-_JM)
Llantas
 | NOTAS
 | Comentar problema de aspa
 | Platicar necesidad de encoders

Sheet: Selecciones
 |  | Configuración |  |  |  |  |  |  | Criterios | Motores | Criterios | LLantas
Criterios | Ponderación | Diferencial | Sincronizado | Tipo carro | Dirección deslizante | Articulada | Pivote | Omnidireccional
Complejidad del sistema de dirección | 4 | 3 | 1 | 5 | 4 | 1 | 1 | 3
Modificaciones en el chasis | 3 | 5 | 2 | 5 | 2 | 1 | 1 | 3
Es holónomo | 7 | 1 | 5 | 1 | 5 | 1 | 5 | 5
Facilidad de implmentar sensores odométricos | 9 | 3 | 2 | 3 | 1 | 3 | 3 | 1
Facilidad para planeación de movimientos | 10 | 3 | 3 | 3 | 2 | 3 | 1 | 3
 | Total | 91 | 93 | 99 | 86 | 71 | 79 | 95
Ponderación de 1 a 10. 10 siendo lo más importante |  | 1 a 5. 5 lo fácil
 |  | Opciones con 95 o más de ponderación total | 2
 |  |  | Tipo carro | Omnidireccional
 |  | Ventajas | Ocupa ruedas más resistentes | Holonómico
 |  |  | Simple | Planeación de movimientos
 |  | Desventajas | No-holonómico | Ruedas con muchas piezas
 |  |  | Planeación de movimientos | Ruedas más caras

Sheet: Hoja 8
 | RPM | Reducción | Torque [Kg cm] | Voltaje [V] | Corriente [mA] |  | Potencia [W] | Precio | Proveedor
Tipo |  |  |  |  | Sin carga | Máxima
Microrreductor | 85 |  | 5 | 6 | 100 | 1500 | 1.1 | 500 | Sandorobotics
 | 100 | 298:1 | 3.4 | 6 | 100 | 1500 | 1 | 500
 | 150 | 210:1 | 3 | 6 | 70 | 1600 | 1.1 | 500
 |  |  |  |  |  |  |  | 122 | AG Electrónica
 |  |  |  |  |  |  |  | 315 | Kinetrónica

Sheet: Recomendaciones y dudas
 | Aspectos relevantes al comprar
0 | Preguntar si alguno de los integrantes cuenta con uno similar
1 | Verificar compatibilidad con llantas a comprar
2 | Para los motores revisar corriente, voltaje, par, reducción
3 | Conseguir el mejor precio
 | Dudas | Respuestas
1 | ¿Cuál va a ser el peso del robot? | 5.5 kg | % kg del peso total del vehículo + 0.6 kg de la pelotas almacenadas (0.06kg es lo que pesa cada una)

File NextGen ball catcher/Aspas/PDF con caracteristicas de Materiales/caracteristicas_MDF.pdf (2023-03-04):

Página 1 de 2

# MDF (Medium Density Fibreboard)

(En España más conocido como DM)

- Definición: Un tablero MDF es un aglomerado elaborado con fibras de madera (que previamente se han desfibrado y eliminado la lignina que poseían) aglutinadas con resinas sintéticas mediante fuerte presión y calor, en seco, hasta alcanzar una densidad media.

La denominación exacta recogida en la normativa es tableros de fibras fabricados por el proceso seco (MDF). Esta denominación es larga y complicada por lo que en el mercado se los conoce como tableros MDF, en algunas ocasiones se utiliza la denominación DM, que no es correcta ya que hace referencia a una marca comercial. Las siglas MDF se corresponden con las iniciales de Medium Density Fiberboards.

- Materiales / Composición: Los materiales que intervienen en su fabricación son fibras de madera, adhesivos, recubrimientos y aditivos. La composición típica suele ser un 80% de fibras, 10% de resinas sintéticas, 7% de agua y hasta un 1 % de parafinas.
- Fibras: se obtienen calentando partículas de madera y forzando su paso a través de los discos rotativos del desfibrador, posteriormente se secan, se encolan y se forma una manta de fibras a la que se aplica presión y calor para obtener el tablero. Las especies de madera más utilizadas en España son los pinos y el eucalipto.

Página 2 de 2

- Adhesivos: los adhesivos que se utilizan dependen de las características y de las propiedades del tablero que se quiera obtener. Urea - formol (UF), Urea - melamina - formol (MUF), Fenol -formaldehído (PF); últimamente se ha empezado a hablar de las colas de isocianato (PMDI) para su posible utilización en las aplicaciones de exterior.
- Cualidades: Se caracterizan por su uniformidad y homogeneidad en todo su espesor, sus caras son lisas y suaves, no presentan problemas para su corte y se mecanizan y molduran con mucha facilidad.
- Aplicaciones/Usos: puertas plafonadas (bastidor y plafones) y planas (paramentos y bastidores), cercos y tapajuntas, muebles en general, muebles de cocina y de baño (en especial para las puertas en relieve), molduras y en general todo tipo de superficies que requieran una superficie suave y moldurada. Industria del mueble en general.

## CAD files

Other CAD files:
NextGen ball catcher/sensor de color modelado/sensor color.0002.dwg
NextGen ball catcher/sensor de color modelado/sensor color.0001.ipt

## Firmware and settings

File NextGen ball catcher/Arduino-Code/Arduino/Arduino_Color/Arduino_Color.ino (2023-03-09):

#define S0 4    // S0 a pin 4
#define S1 5    // S1 a pin 5
#define S2 6    // S2 a pin 6
#define S3 7    // S3 a pin 7
#define salidaTCS 8 // salidaTCS a pin 8
#define Boton 3

int rva[3] = {0,0,0};
int rvaExterior[3] = {0,0,0};
int rvaInterior[3] = {0,0,0};
int rvaLineas[3] = {0,0,0};
int rvaRed[3] = {0,0,0};


void setup() {
  pinMode(Boton, INPUT); // pin 3 como entrada
  
  pinMode(S0, OUTPUT);    // pin 4 como salida
  pinMode(S1, OUTPUT);    // pin 5 como salida
  pinMode(S2, OUTPUT);    // pin 6 como salida
  pinMode(S3, OUTPUT);    // pin 7 como salida
  pinMode(salidaTCS, INPUT);  // pin 8 como salida
  
  digitalWrite(S0,HIGH);  // establece frecuencia de salida
  digitalWrite(S1,LOW);   // del modulo al 20 por ciento
  
  Serial.begin(9600);   // inicializa monitor serie a 9600 bps
}

void loop() {

  reconocerCancha();
  Serial.print("Con las muestras ya podemos distinguir la cancha \n");
  Serial.print("Coloca el sensor donde prefieras y te diremos su posicion actual");
  while(leerEstadoBoton()==1){
  distinguirPosicion();
  }
  
}
void LecturaSensorColor(int RVA[])
{
  digitalWrite(S2,LOW);     // establece fotodiodos
  digitalWrite(S3,LOW);     // con filtro rojo
  RVA[0] = pulseIn(salidaTCS, LOW); // obtiene duracion de pulso de salida del sensor
  delay(200);       // demora de 200 mseg
  
  digitalWrite(S2,HIGH);    // establece fotodiodos
  digitalWrite(S3,HIGH);    // con filtro verde
  RVA[1] = pulseIn(salidaTCS, LOW);  // obtiene duracion de pulso de salida del sensor
  delay(200);       // demora de 200 mseg
  
  digitalWrite(S2,LOW);     // establece fotodiodos
  digitalWrite(S3,HIGH);    // con filtro azul
  RVA[2] = pulseIn(salidaTCS, LOW); // obtiene duracion de pulso de salida del sensor
  delay(200);       // demora de 200 mseg       
}
void imprimirValoresSensorColor(int RVA[])
{  
  //Imprime rojo
  Serial.print("R:");     // muestra texto
  Serial.print(RVA[0]);     // muestra valor de variable rojo
  Serial.print("\t"); // salto de linea
  //Imprime verde
  Serial.print("V:");     // muestra texto
  Serial.print(RVA[1]);      // muestra valor de variable verde
  Serial.print("\t"); // espacio de tabulacion
  Serial.print("\t");     // espacio de tabulacion
  //imprime azul
  Serial.print("A:");     // muestra texto
  Serial.println(RVA[2]);     // muestra valor de variable azul         
}
int leerEstadoBoton()
{
  int Botton = digitalRead(Boton);
  return Botton;
}
void reconocerCancha()
{
  Serial.print("Hola, para reconocer la cancha nececitamos muestras de 4 colores");
  Serial.print("\n"); 
  Serial.print("El primer color es el del exterior de la cancha");
  Serial.print("\n"); // Salto de linea
  Serial.print("Por favor coloca el sensor en el exterior de la cancha y presiona el boton para empezar");
  Serial.print("\n");
  tomarMuestras(rvaExterior);
  Serial.print("Hemos tomado las muestras del exterior de la cancha");
  Serial.print("\n");
  Serial.print("Por favor coloca el sensor en el interior de la cancha y presiona el boton para empezar");
  Serial.print("\n");
  tomarMuestras(rvaInterior);
  Serial.print("Hemos tomado las muestras del interior de la cancha");
  Serial.print("\n");
  Serial.print("Por favor coloca el sensor sobre una linea que conforma la cancha y presiona el boton para empezar");
  Serial.print("\n");
  tomarMuestras(rvaLineas);
  Serial.print("Hemos tomado las muestras de las lineas de la cancha");
  Serial.print("\n");
  Serial.print("Por favor coloca el sensor en la marca debajo de la red de la cancha y presiona el boton para empezar");
  Serial.print("\n");
  tomarMuestras(rvaRed);
  Serial.print("Hemos tomado las muestras de la red de la cancha");
  Serial.print("\n");
}
void tomarMuestras(int RVA[])
{
  int PromedioR = 0;
  int PromedioV = 0;
  int PromedioA = 0;
  while(leerEstadoBoton()== 1); //Esperamos que presione el boton sin hacer nada
  for(int i=0;i<10;i++)
  {
    LecturaSensorColor(rva);
    PromedioR += rva[0];
    PromedioV += rva[1];
    PromedioA += rva[2];
    imprimirValoresSensorColor(rva);
  }
  RVA[0] = PromedioR/10;
  RVA[1] = PromedioV/10;
  RVA[2] = PromedioA/10;
  Serial.print(RVA[0]);
  Serial.print("\t");
  Serial.print(RVA[1]);
  Serial.print("\t");
  Serial.print(RVA[2]);
  Serial.print("\n");
}
void distinguirPosicion()
{
   LecturaSensorColor(rva);
   if(compararRVA(rva,rvaExterior)==1)
   {
    Serial.print("Estas en Exterior de la cancha \n");
   }
   else
   {
    if(compararRVA(rva,rvaInterior)==1)
    {
     Serial.print("Estas en interior de la cancha \n");
    }
    else
    {
      if(compararRVA(rva,rvaLineas)==1)
      {
       Serial.print("Estas sobre una linea de la cancha \n");
      }
      else
      {
        if(compararRVA(rva,rvaRed)==1)
          {
           Serial.print("Estas en la red de la cancha \n");
          }
        else
        {
          Serial.print("Color no reconocido muevete un poco \n");
        }
      }
    }
   }
}
int compararRVA(int RVA1[],int RVA2[])
{
  if(RVA1[0]<=(RVA2[0]+15) && RVA1[0]>=(RVA2[0]-15))
   {
    if(RVA1[1]<=(RVA2[1]+15) && RVA1[1]>=(RVA2[1]-15))
    {
      if(RVA1[2]<=(RVA2[2]+15) && RVA1[2]>=(RVA2[2]-15))
      {
        return 1;
      }
      else
      {
        return 0;
      }
    }
    else
    {
      return 0;
    }
   }
   else
   {
    return 0;
   }
}

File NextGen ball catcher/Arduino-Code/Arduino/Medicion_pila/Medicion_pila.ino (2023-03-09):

void setup() {
  // put your setup code here, to run once:
  Serial.begin(9600);
  pinMode(11,OUTPUT);
}

void loop() {
  // put your main code here, to run repeatedly:
  medirVoltajePila();
}
void medirVoltajePila(){
  int pila = analogRead(A0);
  int pilaM = map(pila,520,1023,0,1023);
  analogWrite(11,pilaM);
  Serial.print(pila);
  Serial.print("\t");
  Serial.print(pilaM);
  Serial.print("\n");
}
